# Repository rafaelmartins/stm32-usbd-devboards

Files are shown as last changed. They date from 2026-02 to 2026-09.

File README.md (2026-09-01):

<!-- github-to-forgejo:notice:start -->
> [!IMPORTANT]
> Development has moved to [https://git.rafaelmartins.com/rafaelmartins/stm32-usbd-devboards](https://git.rafaelmartins.com/rafaelmartins/stm32-usbd-devboards). Please check [https://git.rafaelmartins.com/](https://git.rafaelmartins.com/) for details on how to contribute.
<!-- github-to-forgejo:notice:end -->

# stm32-usbd-devboards

Breadboard-friendly development boards with dedicated USB device connectivity for STM32 microcontrollers.

For documentation please visit: https://rafaelmartins.com/p/stm32-usbd-devboards/

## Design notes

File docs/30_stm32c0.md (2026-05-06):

# STM32C0

The STM32C0 variant is based on the STM32C071K8T6 (ARM Cortex-M0+, 48 MHz) -- the newest addition to the lineup. Like the [STM32F0 variant](10_stm32f0.md), it runs crystal-free using the HSIUSB48 internal oscillator self-calibrated via USB SOF packets, with an optional HSE crystal footprint on the board. The Cortex-M0+ core offers improved power efficiency over the Cortex-M0 in the F0, and this variant provides the largest pin count of the three boards with 2x14 headers exposing 28 GPIO + power pins.

> [!WARNING]
>
> The board includes an HC49 footprint for the HSE crystal. It is very hard (if not impossible) to find a 48 MHz crystal in that format that would fulfill the requirements to be used with the STM32C071K8T6, according to [`AN2867`](https://www.st.com/resource/en/application_note/an2867-guidelines-for-oscillator-design-on-stm8afals-and-stm32-mcusmpus-stmicroelectronics.pdf). When using this board without a USB connection (no HSIUSB48 SOF-calibrated clock available), users may need to install a lower frequency (e.g. 24 MHz) crystal instead, reducing the system clock to that, since the microcontroller does not have a PLL. In such cases, it is recommended to consider the usage of the [STM32F0 variant](10_stm32f0.md) instead.

## Current revision (20251110)

STM32C0 USB Development Board
STM32C0 USB Development Board

**Resources:**

- [Schematic (PDF)](@@/p/stm32-usbd-devboards/kicad/stm32c0-usbd-devboard_20251110_sch.pdf)
- [Interactive BOM](@@/p/stm32-usbd-devboards/kicad/stm32c0-usbd-devboard_20251110_ibom.html)
- [Gerber files (ZIP)](@@/p/stm32-usbd-devboards/kicad/stm32c0-usbd-devboard_20251110_gerber.zip)

KiCad source files are available in the repository under `pcb/stm32c0-usbd-devboard/`. A KiCad symbol for this board (`stm32c0-usbd-devboard`) is provided in `symbols/stm32-usbd-devboards.kicad_sym`.

## Supported microcontrollers

The board uses the CMSIS device identifier `STM32C071xx`.

| Part number | Flash | RAM |
|---|---|---|
| STM32C071K8T6 | 64 KB | 24 KB |

## Pinout

Two 1x14 pin headers at 2.54 mm pitch -- the largest of the three variants.

| J3 (Left) | Pin | J4 (Right) |
|---|---|---|
| GND | 1 | GND |
| 3V3 | 2 | +5V |
| B3 | 3 | A10 |
| B4 | 4 | C6 |
| B5 | 5 | A9 |
| B6 | 6 | A8 |
| B7 | 7 | B2 |
| B8 | 8 | B1 |
| B9 | 9 | B0 |
| C15 | 10 | A7 |
| C14 | 11 | A6 |
| A0 | 12 | A5 |
| A1 | 13 | A4 |
| A2 | 14 | A3 |

> [!NOTE]
> Pins C14 and C15 are **unconnected by default**. Closing solder bridge JP1 connects board pin C15 to GPIO PC15. Closing JP2 connects board pin C14 to GPIO PC14. These solder bridges must **not** be closed if an HSE crystal is installed, as PC14/PC15 are shared with the crystal oscillator pins.

## Clocking

The default clock source is the HSIUSB48 internal oscillator at 48 MHz, self-calibrated via USB SOF packets from the host -- the same approach used by the [F0 variant](10_stm32f0.md). No external crystal is needed for USB operation. For USB, firmware must enable the **Clock Recovery System (CRS)** peripheral synced from USB so that SOF packets continuously calibrate HSIUSB48. Without CRS enabled, the oscillator frequency will drift outside USB tolerance and communication will fail. CRS synced from USB is usually already enabled on reset.

An optional HSE crystal (Y1, HC49 package) can be installed if HSE is required for your application. When using HSE, it serves as the system clock directly -- STM32C0 devices have no PLL -- and HSIUSB48 is not needed. The solder bridges JP1/JP2 must remain open when HSE is installed, since PC14/PC15 serve as the oscillator pins.

The maximum system clock frequency is 48 MHz.

## SWD and DFU bootloader

The C0 variant uses a combined SWD + Bootloader header (J2) -- a single 5-pin vertical header that consolidates the separate SWD and bootloader headers found on the [F0](10_stm32f0.md) and [G4](20_stm32g4.md) variants.

| Pin | Signal |
|---|---|
| 1 | 3V3 |
| 2 | SWCLK |
| 3 | GND |
| 4 | SWDIO |
| 5 | NRST |

> [!NOTE]
> On STM32C0 devices, the BOOT0 pin behavior needs to be configured via option bytes according to the [STM32: Enable Legacy Boot](@@/hardware/stm32-enable-legacy-boot/) document. Refer to the STM32C0 reference manual and the generic [Hardware Build Manual](@@/hardware/build-manual/) for details on USB DFU flashing.

## Board-specific build notes

- **HSE crystal (Y1)**: Optional. 8-48 MHz, HC49 package. Only install if HSE is required.
- **Solder bridges JP1/JP2**: Open by default. Close only if the HSE crystal is **not** installed, to route PC14/PC15 to the header pins.
- **LED (D1)**: Green 3 mm PTH, horizontal mount.

For the complete build process, see the generic [Hardware Build Manual](@@/hardware/build-manual/).

## Firmware development

For project setup, build system configuration, toolchain usage, and flashing instructions, refer to the [cmake-cmsis-stm32 documentation](@@/p/cmake-cmsis-stm32/). The CMSIS device identifier for this board is `STM32C071xx`.

For register-level details on clock configuration, CRS, USB peripheral, and GPIO, refer to the [STM32C0 reference manual (RM0490)](https://www.st.com/resource/en/reference_manual/rm0490-stm32c0-series-advanced-armbased-32bit-mcus-stmicroelectronics.pdf).

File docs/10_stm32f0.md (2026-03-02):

# STM32F0

The STM32F0 variant is based on the STM32F042K4T6/K6T6 (ARM Cortex-M0, 48 MHz) in LQFP-32 package -- the simplest board in the lineup for straightforward USB projects. The STM32F042 integrates an HSI48 internal oscillator that is automatically calibrated by the USB host through SOF packets, enabling crystal-free USB device operation. When no HSE crystal is installed, the two crystal pins (PF0, PF1) can be repurposed as GPIO by closing solder bridges JP1 and JP2.

## Current revision (20250412)

STM32F0 USB Development Board
STM32F0 USB Development Board

**Resources:**

- [Schematic (PDF)](@@/p/stm32-usbd-devboards/kicad/stm32f0-usbd-devboard_20250412_sch.pdf)
- [Interactive BOM](@@/p/stm32-usbd-devboards/kicad/stm32f0-usbd-devboard_20250412_ibom.html)
- [Gerber files (ZIP)](@@/p/stm32-usbd-devboards/kicad/stm32f0-usbd-devboard_20250412_gerber.zip)

KiCad source files are available in the repository under `pcb/stm32f0-usbd-devboard/`. A KiCad symbol for this board (`stm32f0-usbd-devboard`) is provided in `symbols/stm32-usbd-devboards.kicad_sym`.

## Supported microcontrollers

Both parts share the CMSIS device identifier `STM32F042x6` and differ only in flash size.

| Part number | Flash | RAM |
|---|---|---|
| STM32F042K4T6 | 16 KB | 6 KB |
| STM32F042K6T6 | 32 KB | 6 KB |

> [!WARNING]
> The CMSIS device identifier selects headers and startup code, but the **linker script** determines the memory layout. `STM32F042x6` covers both the K4 (16 KB) and K6 (32 KB) parts. You must use a linker script that matches the actual chip populated on your board -- using a linker script for the larger flash variant will compile and link without errors but may produce firmware that writes beyond the physical flash.

## Pinout

Two 1x12 pin headers (2.54 mm pitch) provide power and 20 GPIO.

| J3 (Left) | Pin | J4 (Right) |
|---|---|---|
| GND | 1 | GND |
| 3V3 | 2 | +5V |
| B3 | 3 | A10 |
| B4 | 4 | A9 |
| B5 | 5 | A8 |
| B6 | 6 | B1 |
| B7 | 7 | B0 |
| F1 | 8 | A7 |
| F0 | 9 | A6 |
| A0 | 10 | A5 |
| A1 | 11 | A4 |
| A2 | 12 | A3 |

> [!NOTE]
> Pins F0 and F1 are **unconnected by default**. Closing solder bridge JP1 connects board pin F1 to GPIO PF1. Closing JP2 connects board pin F0 to GPIO PF0. These solder bridges must **not** be closed if an HSE crystal is installed, as PF0/PF1 are shared with the crystal oscillator pins.

## Clocking

The STM32F042 supports two clock sources for USB operation at 48 MHz:

- **HSI48** (default) -- 48 MHz internal RC oscillator, self-calibrated via USB SOF packets from the host. This is the recommended configuration for most USB device applications. Firmware must enable the **Clock Recovery System (CRS)** peripheral synced from USB so that incoming SOF packets continuously trim HSI48. Without CRS, the oscillator frequency drifts outside USB tolerance and communication will fail. CRS synced from USB is usually already enabled on reset.
- **HSE crystal** (optional) -- 8 MHz external crystal (HC49 package), multiplied to 48 MHz via the PLL. Useful when the board is USB-powered but not actively communicating over USB, making SOF-based calibration unavailable. When HSE is used as the system clock source, HSI48 is not needed.

The maximum system clock frequency is 48 MHz regardless of clock source.

## SWD and DFU bootloader

**SWD header (J2)** -- 5-pin vertical header. Signals: 3V3, SWCLK, GND, SWDIO, NRST.

| Pin | Signal |
|---|---|
| 1 | 3V3 |
| 2 | SWCLK |
| 3 | GND |
| 4 | SWDIO |
| 5 | NRST |

**Bootloader header (J5)** -- 2-pin horizontal header for BOOT0. Shorting the pins during power up activates the built-in USB DFU bootloader, allowing firmware upload via the USB connector without an SWD programmer.

For flashing instructions, refer to the generic [Hardware Build Manual](@@/hardware/build-manual/).

## Board-specific build notes

- **HSE crystal (Y1)**: Optional. 8 MHz, HC49 package. Only install if HSE is required for your application.
- **Solder bridges JP1/JP2**: Open by default. Close only if the HSE crystal is **not** installed, to route PF0/PF1 to the header pins.
- **LED (D1)**: Green 3 mm PTH, horizontal mount.

For the complete build process, see the generic [Hardware Build Manual](@@/hardware/build-manual/).

## Firmware development

For project setup, build system configuration, toolchain usage, and flashing instructions, refer to the [cmake-cmsis-stm32 documentation](@@/p/cmake-cmsis-stm32/). The CMSIS device identifier for this board is `STM32F042x6`.

For register-level details on clock configuration, CRS, USB peripheral, and all other on-chip peripherals, refer to the [STM32F0x1/F0x2/F0x8 reference manual (RM0091)](https://www.st.com/resource/en/reference_manual/rm0091-stm32f0x1stm32f0x2stm32f0x8-advanced-armbased-32bit-mcus-stmicroelectronics.pdf).

## Legacy revision: 20241212

This was the first revision of the STM32F0 board. Compared to the current revision (20250412):

- HSE crystal support was not present
- The pin header assignments were different (F0/F1 swapped)

Users building from this revision should refer to its schematic and iBOM for the correct pinout and component placement.

STM32F0 USB Development Board (revision 20241212)
STM32F0 USB Development Board (revision 20241212)

**Resources:**

- [Schematic (PDF)](@@/p/stm32-usbd-devboards/kicad/stm32f0-usbd-devboard_20241212_sch.pdf)
- [Interactive BOM](@@/p/stm32-usbd-devboards/kicad/stm32f0-usbd-devboard_20241212_ibom.html)
- [Gerber files (ZIP)](@@/p/stm32-usbd-devboards/kicad/stm32f0-usbd-devboard_20241212_gerber.zip)

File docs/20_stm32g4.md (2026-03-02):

# STM32G4

The STM32G4 variant is based on the STM32G431K6T6/K8T6/KBT6 (ARM Cortex-M4 with single-precision FPU, 170 MHz). It provides significantly more processing power than the [F0](10_stm32f0.md) and [C0](30_stm32c0.md) variants, with up to 128 KB of flash and hardware floating-point support.

## Current revision (20250412)

STM32G4 USB Development Board
STM32G4 USB Development Board

**Resources:**

- [Schematic (PDF)](@@/p/stm32-usbd-devboards/kicad/stm32g4-usbd-devboard_20250412_sch.pdf)
- [Interactive BOM](@@/p/stm32-usbd-devboards/kicad/stm32g4-usbd-devboard_20250412_ibom.html)
- [Gerber files (ZIP)](@@/p/stm32-usbd-devboards/kicad/stm32g4-usbd-devboard_20250412_gerber.zip)

KiCad source files are available in the repository under `pcb/stm32g4-usbd-devboard/`. A KiCad symbol for this board (`stm32g4-usbd-devboard`) is provided in `symbols/stm32-usbd-devboards.kicad_sym`.

## Supported microcontrollers

All three parts share the same LQFP-32 package and pinout, differing only in flash size. They use the CMSIS device identifier `STM32G431xx`.

| Part number | Flash | RAM |
|---|---|---|
| STM32G431K6T6 | 32 KB | 32 KB |
| STM32G431K8T6 | 64 KB | 32 KB |
| STM32G431KBT6 | 128 KB | 32 KB |

> [!WARNING]
> The CMSIS device identifier selects headers and startup code, but the **linker script** determines the memory layout. `STM32G431xx` covers all three parts above despite their different flash sizes. You must use a linker script that matches the actual chip populated on your board -- using a linker script for a larger flash variant will compile and link without errors but may produce firmware that writes beyond the physical flash.

## Pinout

The board breaks out GPIO and power across two 1x10 pin headers (2.54 mm pitch), one on each side. PF0/PF1 are dedicated to the 24 MHz HSE crystal on this variant and are not available on the pin headers.

| J3 (Left) | Pin | J4 (Right) |
|---|---|---|
| GND | 1 | GND |
| 3V3 | 2 | +5V |
| B4 | 3 | A10 |
| B5 | 4 | A9 |
| B6 | 5 | A8 |
| B7 | 6 | B0 |
| A0 | 7 | A7 |
| A1 | 8 | A6 |
| A2 | 9 | A5 |
| A3 | 10 | A4 |

## Clocking

The STM32G4 supports crystal-free USB operation via HSI48 with the **Clock Recovery System (CRS)**, which uses USB SOF packets from the host to keep HSI48 within USB tolerance -- the same mechanism used on the [F0](10_stm32f0.md) and [C0](30_stm32c0.md) variants.

However, unlike on the F0 and C0, HSI48 cannot be used as the system clock or as the PLL source on the G4. When no HSE crystal is installed, the system clock must come from HSI -- the internal 16 MHz RC oscillator -- directly or via PLL. RC oscillators drift with temperature and supply voltage, so system clock accuracy in this configuration depends entirely on HSI's tolerance. CRS keeps USB working, but any other timing-sensitive function (UART baud rates, ADC sampling, timers) inherits that drift.

The optional 24 MHz HSE crystal (Y1) provides a stable, accurate clock reference for the system and is recommended. When installed, the PLL can derive both the system clock and a 48 MHz USB clock from the HSE input, and HSI48 is not needed.

## Power filtering

Ferrite bead FB1 (600 ohm @ 100 MHz, 0603 SMD) is placed on the analog/USB power rail for noise filtering.

Solder bridge JP1 ("No FB1") can be closed to bypass FB1 if the ferrite bead is unavailable or unnecessary for the application. JP1 is open by default.

> [!NOTE]
> This power filtering arrangement is unique to the G4 variant.

## SWD, SWO, and DFU bootloader

**SWD header (J2)** -- 6-pin horizontal header with the following signals:

| Pin | Signal |
|---|---|
| 1 | 3V3 |
| 2 | SWCLK |
| 3 | GND |
| 4 | SWDIO |
| 5 | NRST |
| 6 | SWO |

SWO (Serial Wire Output) on PB3 provides trace output, enabling ITM-based printf-style debugging or tools like [MCUViewer](https://github.com/klonyyy/MCUViewer).

**Bootloader header (J5)** -- 2-pin horizontal header for BOOT0. Shorting the pins during power up activates the built-in USB DFU bootloader, allowing firmware flashing over USB without a hardware debugger.

For flashing instructions, refer to the generic [Hardware Build Manual](@@/hardware/build-manual/).

## Board-specific build notes

- **HSE crystal (Y1)**: 24 MHz, HC49 package. Optional, but recommended -- provides a more accurate clock reference for the system clock. Without it, USB still works via HSI48 with CRS, but HSI48 **cannot** be used as the system clock.
- **Ferrite bead (FB1)**: 600 ohm @ 100 MHz, 0603 SMD. Recommended for mixed-signal applications. Can be bypassed by closing JP1.
- **Solder bridge JP1**: Open by default. Close only if FB1 is not installed.
- **LED (D1)**: Green 3 mm PTH, horizontal mount.

For the complete build process, see the generic [Hardware Build Manual](@@/hardware/build-manual/).

## Firmware development

For project setup, build system configuration, toolchain usage, and flashing instructions, refer to the [cmake-cmsis-stm32 documentation](@@/p/cmake-cmsis-stm32/). The CMSIS device identifier for this board is `STM32G431xx`.

For register-level details on peripherals, clocking, and CRS configuration, refer to the [STM32G4 reference manual (RM0440)](https://www.st.com/resource/en/reference_manual/rm0440-stm32g4-series-advanced-armbased-32bit-mcus-stmicroelectronics.pdf).

## Legacy revision: 20250402

This revision is nearly identical to the current one (20250412), with only minor fixes. The pinout, components, and functionality are the same.

STM32G4 USB Development Board (revision 20250402)
STM32G4 USB Development Board (revision 20250402)

**Resources:**

- [Schematic (PDF)](@@/p/stm32-usbd-devboards/kicad/stm32g4-usbd-devboard_20250402_sch.pdf)
- [Interactive BOM](@@/p/stm32-usbd-devboards/kicad/stm32g4-usbd-devboard_20250402_ibom.html)
- [Gerber files (ZIP)](@@/p/stm32-usbd-devboards/kicad/stm32g4-usbd-devboard_20250402_gerber.zip)

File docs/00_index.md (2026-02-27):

---
menu: Main
---

**Breadboard-friendly development boards with dedicated USB device connectivity for STM32 microcontrollers.**

## Overview

Nucleo-32 boards have a problem: the only USB port is consumed by the built-in ST-Link programmer, leaving no independent USB connection for the microcontroller's device peripheral. These boards fix that -- a dedicated USB Mini-B connector wired straight to the MCU, separate from the SWD programmer, so you can develop USB firmware the way it should work.

## Key highlights

- **Independent USB Mini-B** -- dedicated device port, not shared with the programmer
- **USB DFU bootloader** -- flash firmware over USB, no programmer required
- **Breadboard-compatible** -- 2.54 mm pitch headers, fits right into your prototyping setup
- **Mostly through-hole** -- designed for hand soldering with PTH components
- **SWD header** -- connect your hardware debugger when you need it
- **On-board power and protection** -- 5 V to 3.3 V LDO from USB, ESD protection on data lines

## Hardware variants

Pick the microcontroller that fits your project.

### STM32F0

STM32F0 board render
[STM32F0](10_stm32f0.md) PCB render

Cortex-M0 at 48 MHz. Crystal-free USB via HSI48 self-calibrated by the host -- solder two bridges and you get the crystal pins back as GPIO. The simplest option for straightforward USB projects.

[STM32F0 variant details](10_stm32f0.md)

### STM32G4

STM32G4 board render
[STM32G4](20_stm32g4.md) PCB render

Cortex-M4F at 170 MHz with FPU and SWO trace output. Crystal-free USB via HSI48 self-calibrated by the host is possible, but the crystal is recommended. You get significantly more processing power and up to 128 KB of flash. The choice when your USB device needs to do real computation or deal with analog signals.

[STM32G4 variant details](20_stm32g4.md)

### STM32C0

STM32C0 board render
[STM32C0](30_stm32c0.md) PCB render

Cortex-M0+ at 48 MHz. Crystal-free USB like the F0 variant, with 64 KB flash, 24 KB RAM, and the largest pin count of the three -- 28 GPIO + power pins across 2x 1x14 headers.

[STM32C0 variant details](30_stm32c0.md)

## Explore further

- [STM32F0](10_stm32f0.md) -- Cortex-M0 variant with crystal-free USB
- [STM32G4](20_stm32g4.md) -- Cortex-M4F variant with FPU and SWO
- [STM32C0](30_stm32c0.md) -- Cortex-M0+ variant with the largest pin count
- [Build manual](@@/hardware/build-manual/) -- generic assembly and soldering instructions
- [cmake-cmsis-stm32](@@/p/cmake-cmsis-stm32/) -- CMake module for bare-metal STM32 firmware development
- [Source files on GitHub](https://github.com/rafaelmartins/stm32-usbd-devboards) -- KiCad schematics, PCB layouts, and Gerber files

Hardware released under [CERN-OHL-S-2.0](https://github.com/rafaelmartins/stm32-usbd-devboards/blob/main/LICENSE).

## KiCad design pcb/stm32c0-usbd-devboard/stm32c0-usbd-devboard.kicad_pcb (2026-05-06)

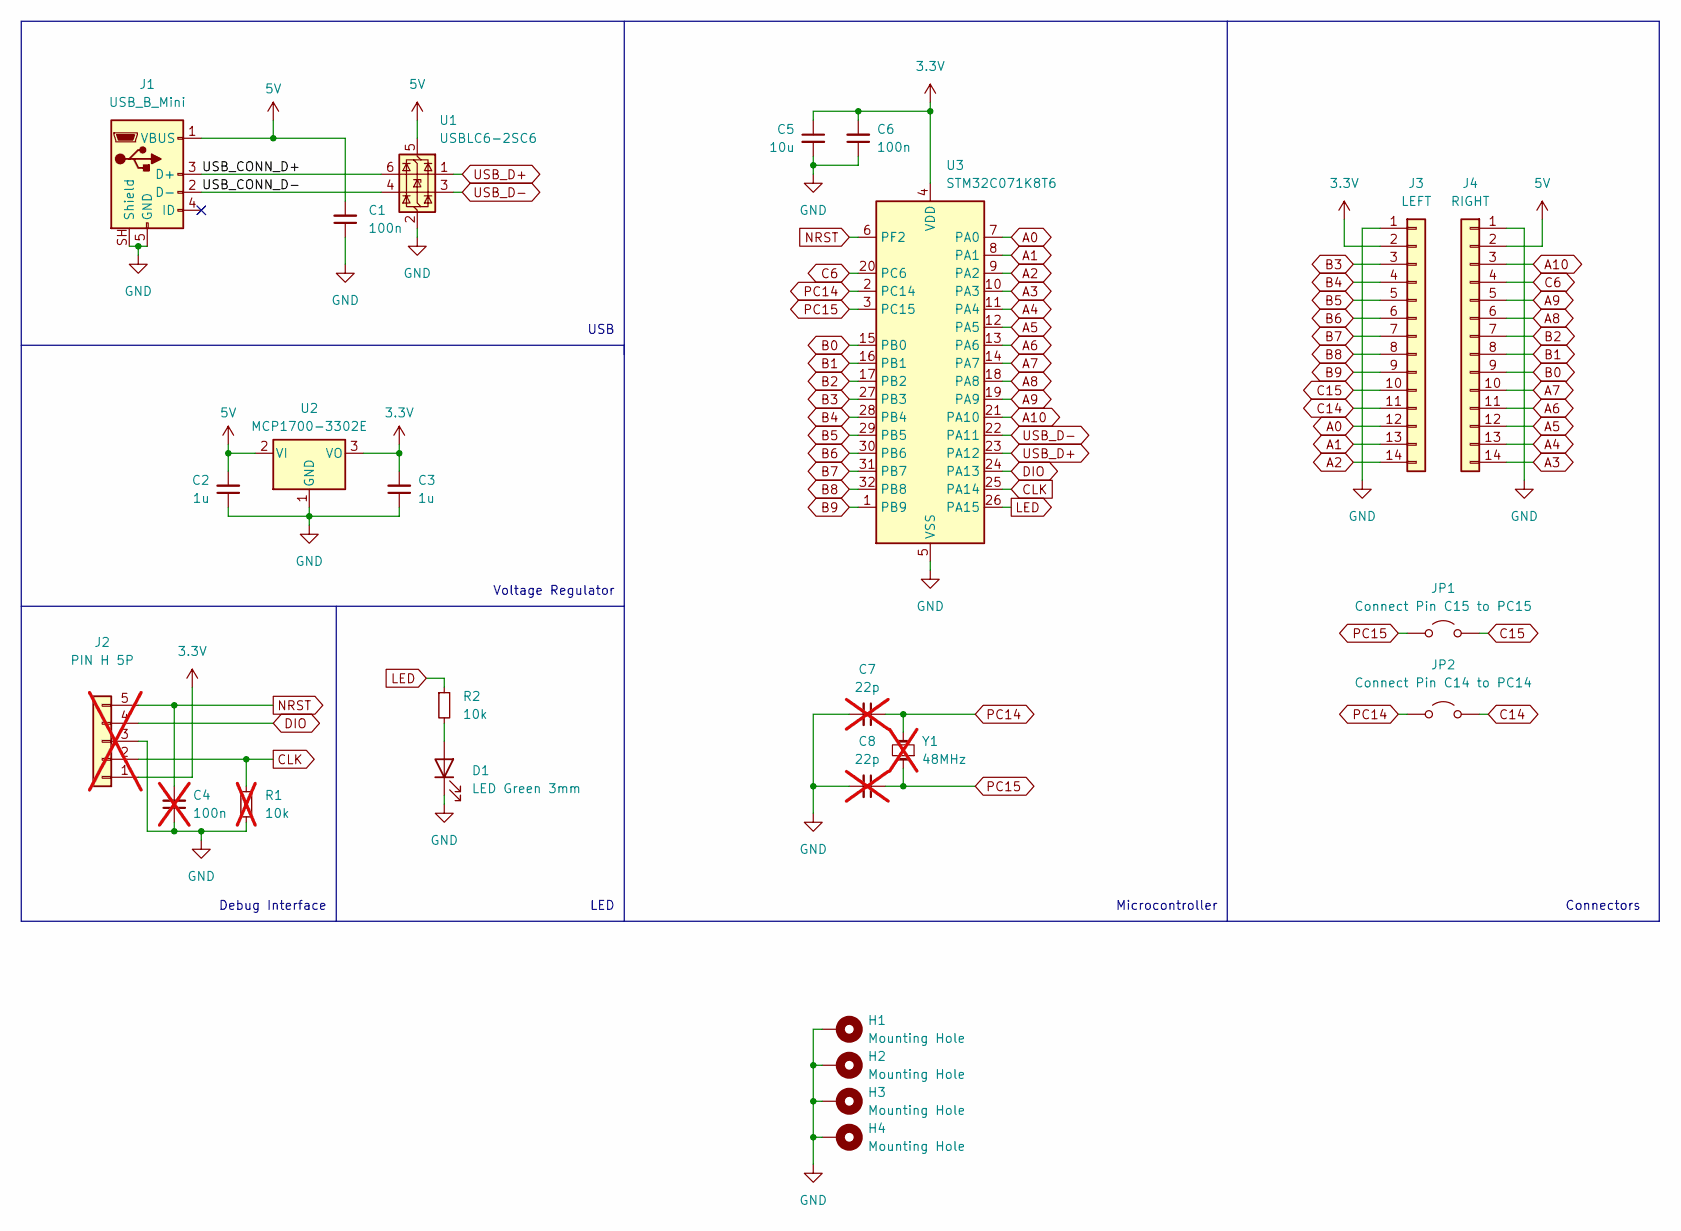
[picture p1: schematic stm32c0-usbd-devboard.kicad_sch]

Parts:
C1, C6: 100n; C_TDK_FA28; MPN FA28X7R1H104KNU06
C2, C3: 1u; C_TDK_FA28; MPN FA28X7R1E105KRU06
C4: 100n; C_TDK_FA28; MPN FA28X7R1H104KNU06; not fitted
C5: 10u; C_TDK_FA26; MPN FA26X7R1E106KRU06
C7, C8: 22p; C_Disc_D3.8mm_W2.6mm_P2.50mm; MPN FA28X7R1H104KNU06; not fitted
D1: LED Green 3mm; LED_D3.0mm_Horizontal_O1.27mm_Z2.0mm; MPN OVLBG4C7
H1, H2, H3, H4: Mounting Hole; MountingHole_2.2mm_M2_Pad_Via
J1: USB_B_Mini; USB_Mini-B_PTH; MPN GMSB0522132EU
J2: PIN H 5P; PinHeader_Bootloader_SWD_1x05_P2.54mm_Vertical; not fitted
J3: LEFT; PinHeader_DevBoard_Left_Connector_1x14_P2.54mm_Vertical
J4: RIGHT; PinHeader_DevBoard_Right_Connector_1x14_P2.54mm_Vertical
JP1: Connect Pin C15 to PC15; SolderJumper-2_P1.3mm_Open_TrianglePad1.0x1.5mm
JP2: Connect Pin C14 to PC14; SolderJumper-2_P1.3mm_Open_TrianglePad1.0x1.5mm
R1: 10k; R_YAGEO_MFR-25FTE52_Horizontal; MPN MFR-25FTE52-10K; not fitted
R2: 10k; R_YAGEO_MFR-25FTE52_Horizontal; MPN MFR-25FTE52-10K
U1: USBLC6-2SC6; SOT-23-6; MPN USBLC6-2SC6
U2: MCP1700-3302E; TO-92_Inline_Wide; MPN MCP1700-3302E/TO
U3: STM32C071K8T6; LQFP-32_7x7mm_P0.8mm
Y1: 48MHz; Crystal_HC49-4H_Vertical; not fitted

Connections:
3.3V: C3.2, C5.1, C6.2, J2.1, J3.2, U2.3 (VO), U3.4 (VDD)
5V: C1.2, C2.2, J1.1 (VBUS), J4.2, U1.5 (VBUS), U2.2 (VI)
/USB_CONN_D+: J1.3 (D+), U1.6 (I/O1)
/USB_CONN_D-: J1.2 (D-), U1.4 (I/O2)
A0: J3.12, U3.7 (PA0)
A1: J3.13, U3.8 (PA1)
A2: J3.14, U3.9 (PA2)
A3: J4.14, U3.10 (PA3)
A4: J4.13, U3.11 (PA4)
A5: J4.12, U3.12 (PA5)
A6: J4.11, U3.13 (PA6)
A7: J4.10, U3.14 (PA7)
A8: J4.6, U3.18 (PA8)
A9: J4.5, U3.19 (PA9)
A10: J4.3, U3.21 (PA10)
B0: J4.9, U3.15 (PB0)
B1: J4.8, U3.16 (PB1)
B2: J4.7, U3.17 (PB2)
B3: J3.3, U3.27 (PB3)
B4: J3.4, U3.28 (PB4)
B5: J3.5, U3.29 (PB5)
B6: J3.6, U3.30 (PB6)
B7: J3.7, U3.31 (PB7)
B8: J3.8, U3.32 (PB8)
B9: J3.9, U3.1 (PB9)
C6: J4.4, U3.20 (PC6)
C14: J3.11, JP2.1 (A)
C15: J3.10, JP1.1 (A)
CLK: J2.2, R1.1, U3.25 (PA14)
DIO: J2.4, U3.24 (PA13)
GND: C1.1, C2.1, C3.1, C4.1, C5.2, C6.1, C7.2, C8.2, D1.1 (K), H1.1 (1_1), H2.1 (1_1), H3.1 (1_1), H4.1 (1_1), J1.5 (GND), J1.SH (Shield), J2.3, J3.1, J4.1, R1.2, U1.2 (GND), U2.1 (GND), U3.5 (VSS)
LED: R2.1, U3.26 (PA15)
NRST: C4.2, J2.5, U3.6 (PF2)
unnamed: D1.2 (A), R2.2
PC14: C7.1, JP2.2 (B), U3.2 (PC14), Y1.2
PC15: C8.1, JP1.2 (B), U3.3 (PC15), Y1.1
USB_D+: U1.1 (I/O1), U3.23 (PA12)
USB_D-: U1.3 (I/O2), U3.22 (PA11)

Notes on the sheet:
Debug Interface
LED
Microcontroller
Connectors
Voltage Regulator
USB

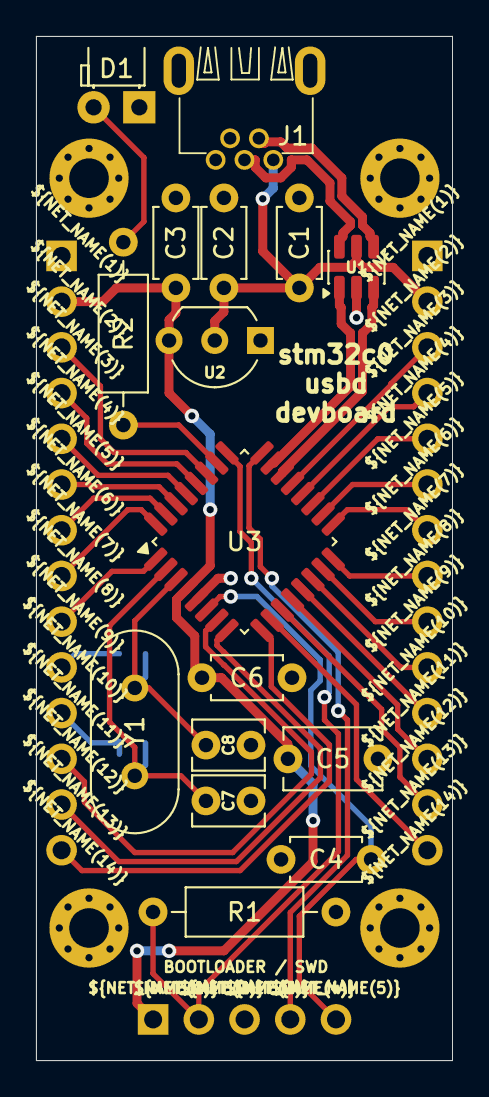
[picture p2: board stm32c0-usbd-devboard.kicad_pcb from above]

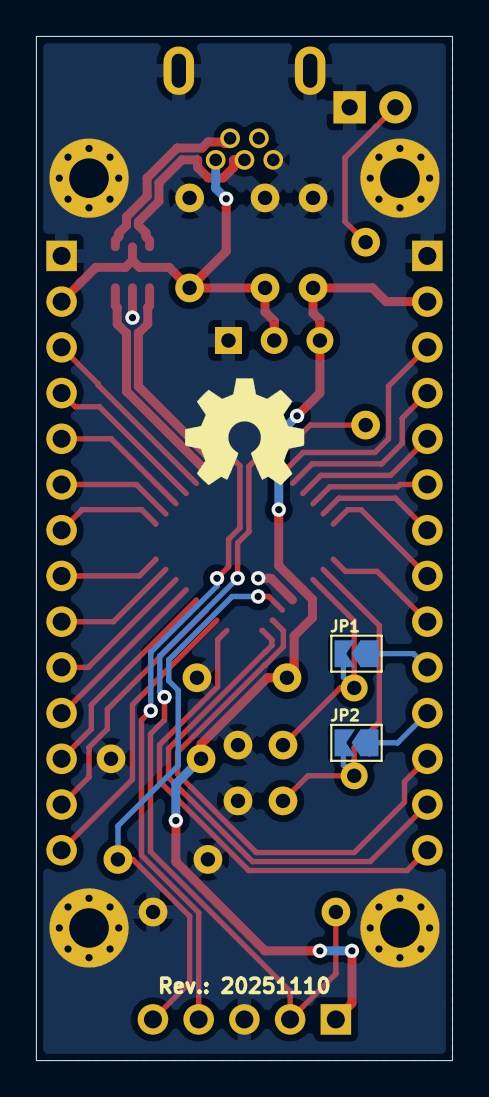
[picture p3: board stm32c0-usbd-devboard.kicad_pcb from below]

Board: 2 copper layers, 23.1 x 56.9 mm, 25 parts (4 on the bottom side), 38 nets.

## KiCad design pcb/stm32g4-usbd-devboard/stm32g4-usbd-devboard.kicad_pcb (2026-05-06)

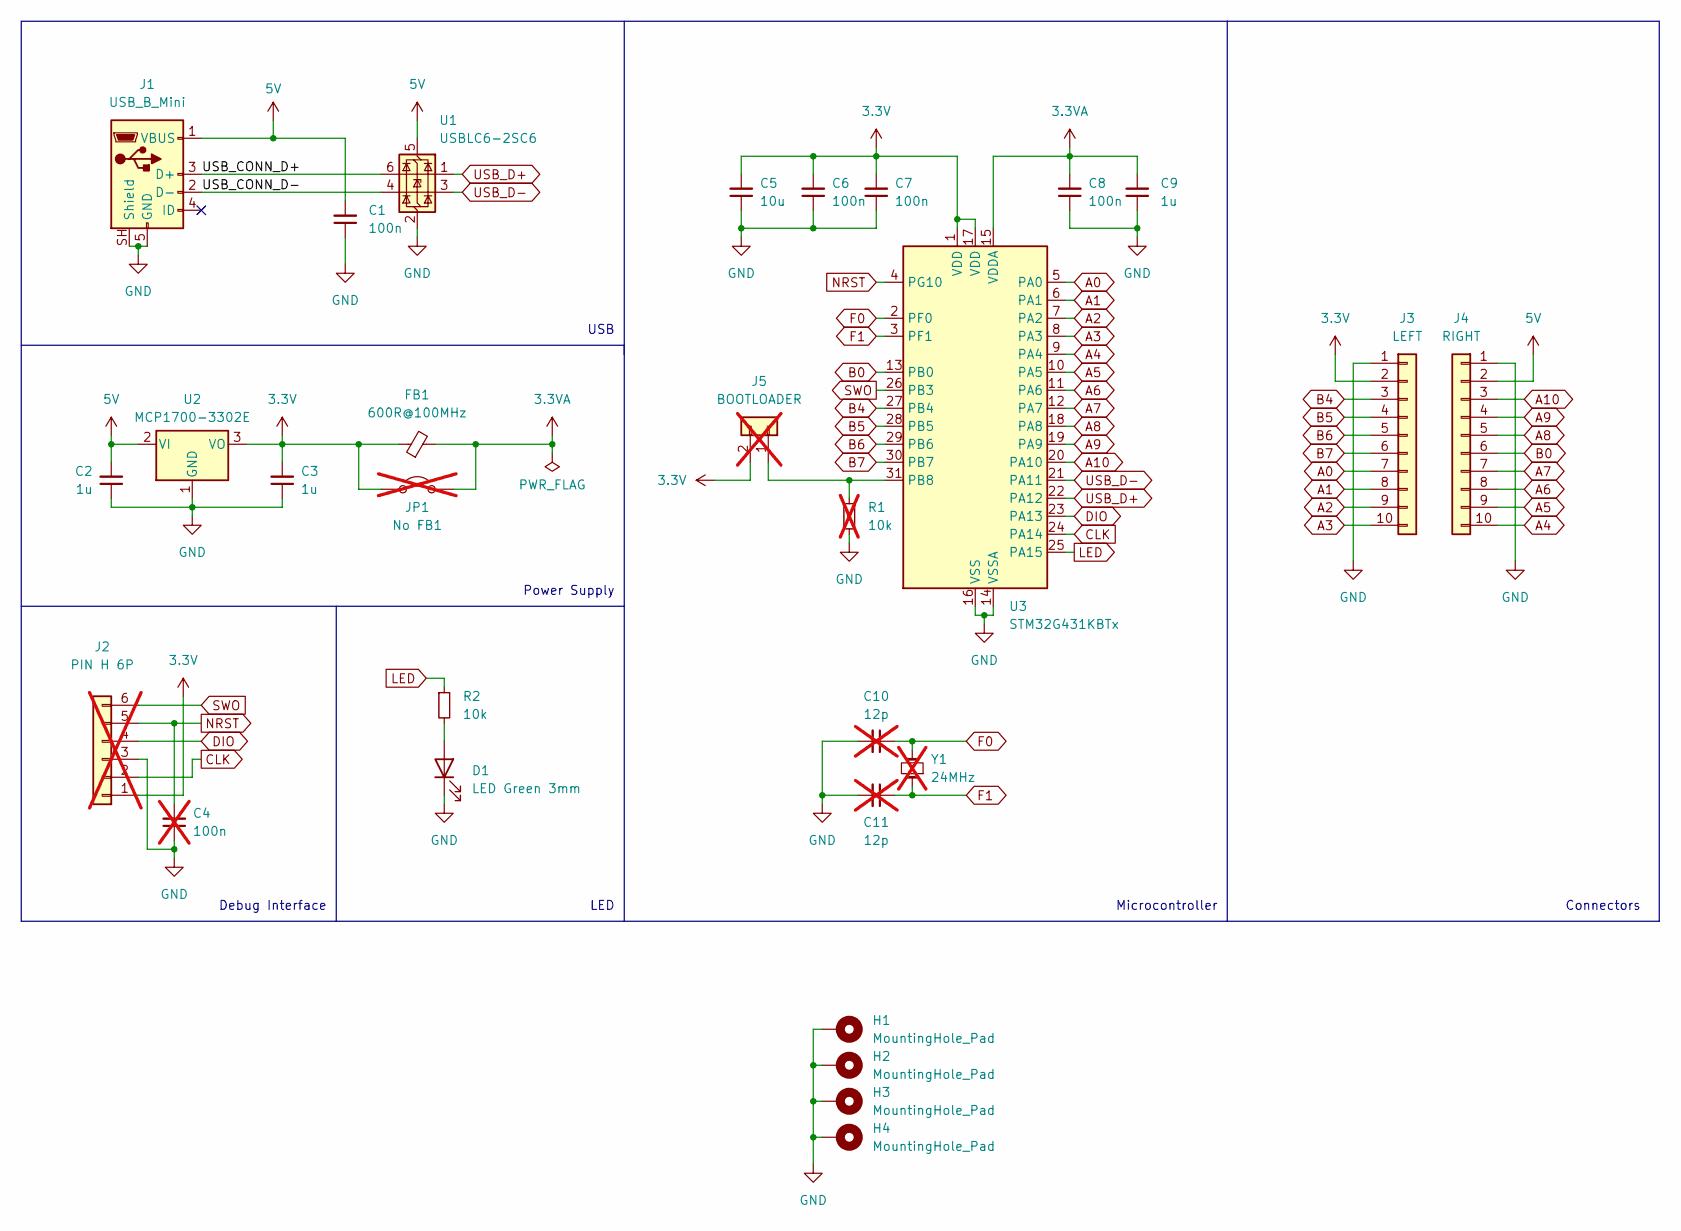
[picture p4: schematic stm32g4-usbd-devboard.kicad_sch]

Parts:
C1, C6, C7, C8: 100n; C_TDK_FA28; MPN FA28X7R1H104KNU06
C2, C3: 1u; C_TDK_FA28; MPN FA28X7R1E105KRU06
C4: 100n; C_TDK_FA28; MPN FA28X7R1H104KNU06; not fitted
C5: 10u; C_TDK_FA26; MPN FA26X7R1E106KRU06
C9: 1u; C_TDK_FA28; MPN FA28X7R1H104KNU06
C10, C11: 12p; C_Disc_D3.8mm_W2.6mm_P2.50mm; MPN FA28X7R1E105KRU06; not fitted
D1: LED Green 3mm; LED_D3.0mm_Horizontal_O1.27mm_Z2.0mm; MPN OVLBG4C7
FB1: 600R@100MHz; L_0603_1608Metric_Pad1.05x0.95mm_HandSolder
H1, H2, H3, H4: MountingHole_Pad; MountingHole_2.2mm_M2_Pad_Via
J1: USB_B_Mini; USB_Mini-B_PTH; MPN GMSB0522132EU
J2: PIN H 6P; PinHeader_SWD_1x06_P2.54mm_Horizontal; not fitted
J3: LEFT; PinHeader_DevBoard_Left_Connector_1x10_P2.54mm_Vertical
J4: RIGHT; PinHeader_DevBoard_Right_Connector_1x10_P2.54mm_Vertical
J5: BOOTLOADER; PinHeader_Bootloader_1x02_P2.54mm_Horizontal; not fitted
JP1: No FB1; SolderJumper-2_P1.3mm_Open_TrianglePad1.0x1.5mm; not fitted
R1: 10k; R_YAGEO_MFR-25FTE52_Horizontal; MPN MFR-25FTE52-10K; not fitted
R2: 10k; R_YAGEO_MFR-25FTE52_Horizontal; MPN MFR-25FTE52-10K
U1: USBLC6-2SC6; SOT-23-6; MPN USBLC6-2SC6
U2: MCP1700-3302E; TO-92_Inline_Wide; MPN MCP1700-3302E/TO
U3: STM32G431KBTx; LQFP-32_7x7mm_P0.8mm
Y1: 24MHz; Crystal_HC49-4H_Vertical; not fitted

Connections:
3.3V: C3.2, C5.2, C6.2, C7.2, FB1.1, J2.1, J3.2, J5.2, JP1.2 (B), U2.3 (VO), U3.1 (VDD), U3.17 (VDD)
3.3VA: C8.2, C9.2, FB1.2, JP1.1 (A), U3.15 (VDDA)
5V: C1.2, C2.2, J1.1 (VBUS), J4.2, U1.5 (VBUS), U2.2 (VI)
/USB_CONN_D+: J1.3 (D+), U1.6 (I/O1)
/USB_CONN_D-: J1.2 (D-), U1.4 (I/O2)
A0: J3.7, U3.5 (PA0)
A1: J3.8, U3.6 (PA1)
A2: J3.9, U3.7 (PA2)
A3: J3.10, U3.8 (PA3)
A4: J4.10, U3.9 (PA4)
A5: J4.9, U3.10 (PA5)
A6: J4.8, U3.11 (PA6)
A7: J4.7, U3.12 (PA7)
A8: J4.5, U3.18 (PA8)
A9: J4.4, U3.19 (PA9)
A10: J4.3, U3.20 (PA10)
B0: J4.6, U3.13 (PB0)
B4: J3.3, U3.27 (PB4)
B5: J3.4, U3.28 (PB5)
B6: J3.5, U3.29 (PB6)
B7: J3.6, U3.30 (PB7)
CLK: J2.2, U3.24 (PA14)
DIO: J2.4, U3.23 (PA13)
F0: C10.1, U3.2 (PF0), Y1.2
F1: C11.1, U3.3 (PF1), Y1.1
GND: C1.1, C2.1, C3.1, C4.1, C5.1, C6.1, C7.1, C8.1, C9.1, C10.2, C11.2, D1.1 (K), H1.1 (1_1), H2.1 (1_1), H3.1 (1_1), H4.1 (1_1), J1.5 (GND), J1.SH (Shield), J2.3, J3.1, J4.1, R1.2, U1.2 (GND), U2.1 (GND), U3.14 (VSSA), U3.16 (VSS), U3.32 (VSS)
LED: R2.1, U3.25 (PA15)
NRST: C4.2, J2.5, U3.4 (PG10)
unnamed: D1.2 (A), R2.2
unnamed: J5.1, R1.1, U3.31 (PB8)
SWO: J2.6, U3.26 (PB3)
USB_D+: U1.1 (I/O1), U3.22 (PA12)
USB_D-: U1.3 (I/O2), U3.21 (PA11)

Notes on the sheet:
Debug Interface
LED
Microcontroller
Connectors
Power Supply
USB

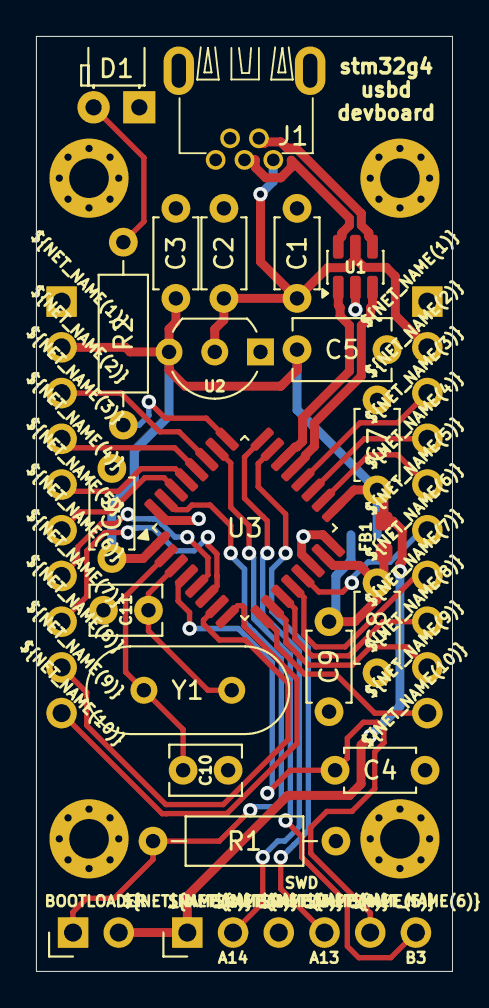
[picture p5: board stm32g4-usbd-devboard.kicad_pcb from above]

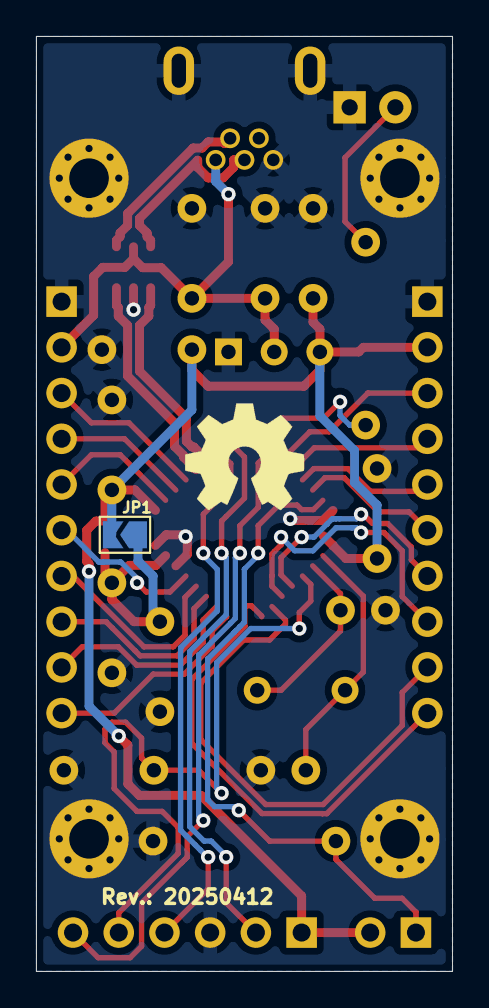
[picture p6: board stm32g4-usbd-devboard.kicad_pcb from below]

Board: 2 copper layers, 23.1 x 51.9 mm, 29 parts (3 on the bottom side), 33 nets.

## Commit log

2025-04-12 pcb: import sources as they were last produced
    [stm32f0-usbd-devboard.kicad_pcb, stm32f0-usbd-devboard.kicad_sch, stm32g4-usbd-devboard.kicad_pcb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]
2025-04-12 pcb: consolidate kicad libraries
    [stm32f0-usbd-devboard.kicad_pcb, stm32f0-usbd-devboard.kicad_sch, stm32g4-usbd-devboard.kicad_pcb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]
2025-04-13 pcb: *: new revision: 20250412
    [stm32f0-usbd-devboard.kicad_pcb, stm32f0-usbd-devboard.kicad_sch, stm32g4-usbd-devboard.kicad_pcb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]
2025-04-17 build: add github actions workflow to build and deploy pcb assets
2025-04-19 symbols: added kicad symbols
2025-06-12 pcb: f0: fix crystal capacitor values
    trivial fix not affecting any physical layers, not bumping revision.
    [stm32f0-usbd-devboard.kicad_pcb, stm32f0-usbd-devboard.kicad_sch]
2025-07-20 pcb: f0: g4: minor schematic symbol fixes
    trivial fix not affecting any board files, not bumping revision.
    [stm32f0-usbd-devboard.kicad_sch, stm32g4-usbd-devboard.kicad_sch]
2025-07-20 pcb: f0: g4: delete schematic pdfs
    they are now generated on demand by github actions
2025-08-07 build: use kicad 9.0 nightly for ci
2025-12-07 rework pcb asset build pipeline
2026-02-09 pcb: c0: initial revision 20251110
    [stm32c0-usbd-devboard.kicad_pcb, stm32c0-usbd-devboard.kicad_sch]
2026-02-09 pcb: c0: added pcb asset build config
2026-02-21 build: rename action rafaelmartins/website/{kicad,hardware}
2026-02-22 Revert "build: rename action rafaelmartins/website/{kicad,hardware}"
    This reverts commit cf9ebdc07a408e897589e579c1503bb26a4f33f2.
2026-02-22 pcb: update asset gen config files
2026-02-27 pcb: c0: fix crystal frequency
    no physical layer changes, no revision bump.
    [stm32c0-usbd-devboard.kicad_pcb, stm32c0-usbd-devboard.kicad_sch]
2026-03-01 symbols: add stm32c0-usbd-devboard symbol
2026-03-02 docs: mention kicad symbols
2026-05-06 docs: add stm32c0 crystal warning
2026-05-06 pcb: symbols: upgrade footprints and symbols to kicad 10
2026-05-06 pcb: f0: upgrade to kicad 10
    [stm32f0-usbd-devboard.kicad_pcb, stm32f0-usbd-devboard.kicad_sch]
2026-05-06 pcb: g4: upgrade to kicad 10
    [stm32g4-usbd-devboard.kicad_pcb, stm32g4-usbd-devboard.kicad_sch]
2026-05-06 pcb: c0: upgrade to kicad 10
    [stm32c0-usbd-devboard.kicad_pcb, stm32c0-usbd-devboard.kicad_sch]

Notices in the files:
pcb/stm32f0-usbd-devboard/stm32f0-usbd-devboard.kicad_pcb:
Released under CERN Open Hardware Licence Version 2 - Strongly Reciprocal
